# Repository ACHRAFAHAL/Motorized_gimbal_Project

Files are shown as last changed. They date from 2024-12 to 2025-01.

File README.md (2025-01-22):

# Motorized_gimbal_Project

Motorized 3-axis gimbal using Arduino! This project stabilizes cameras with gyroscopic sensors and servomotors for smooth footage.

## Project Overview:
The project is a gimbal system created using an Arduino platform to stabilize a mounted payload (camera) and maintain its orientation. The gimbal compensates for external movements, ensuring smooth, stable footage or data collection.



## Components Used:
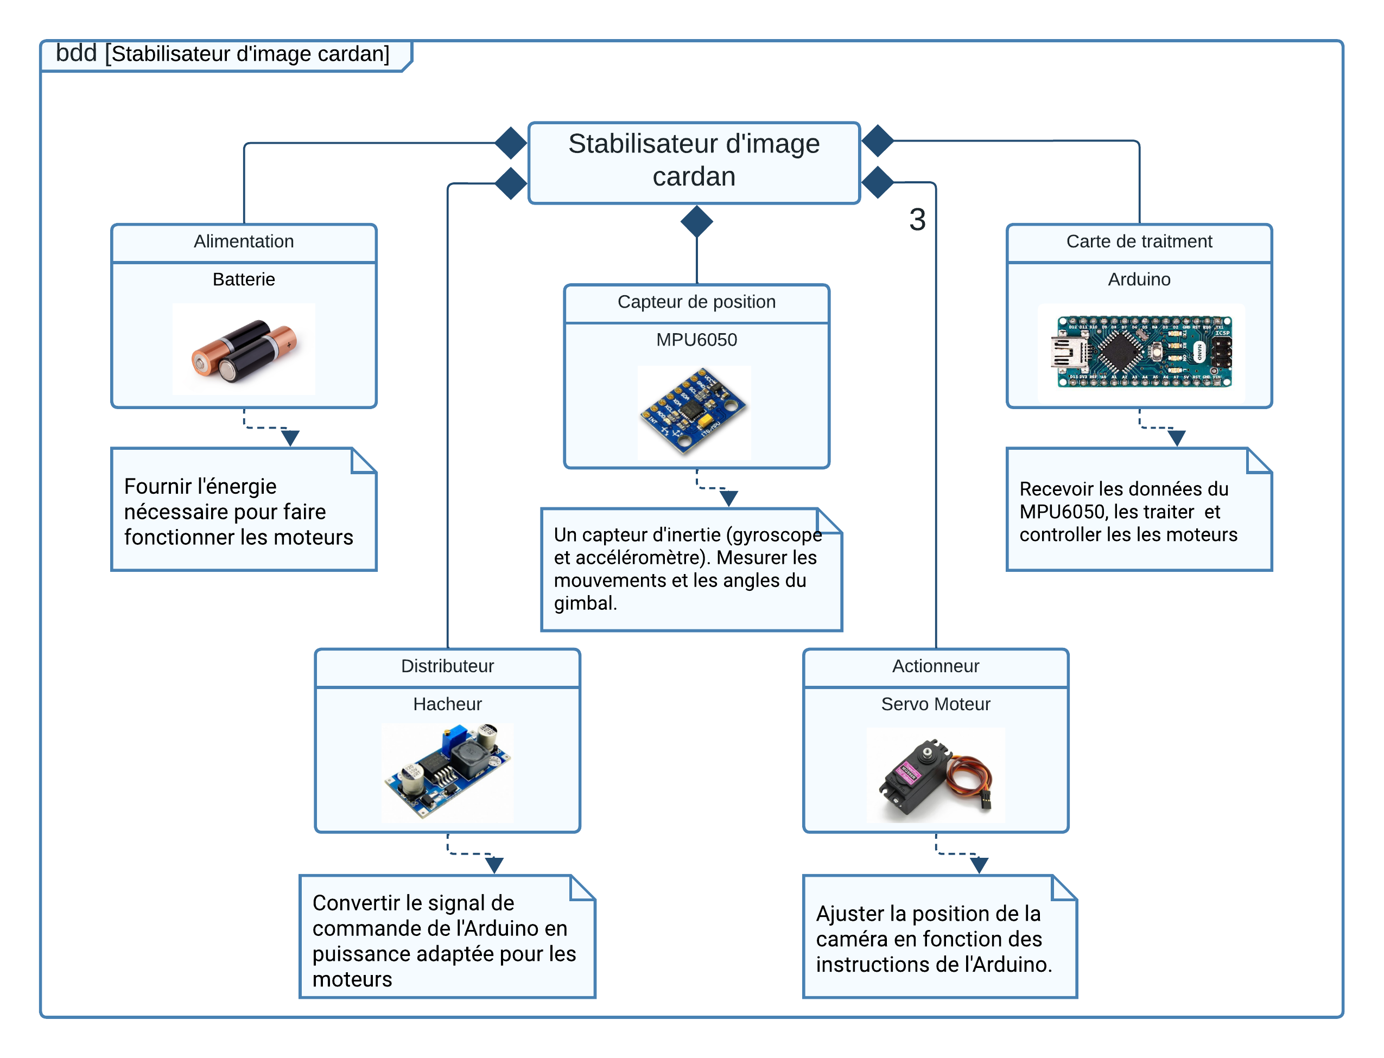
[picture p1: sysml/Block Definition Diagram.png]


[Arduino NANO board](https://www.amazon.com/LAFVIN-Board-ATmega328P-Micro-Controller-Arduino/dp/B07G99NNXL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)

[MPU6050 IMU sensors](https://www.amazon.com/MPU-6050-MPU6050-Accelerometer-Gyroscope-Converter/dp/B07RXQGGJX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) (Accelerometer and Gyroscope) for motion detection

Motors ([servomotors: MG996R](https://www.amazon.com/MG996R-Digital-Waterproof-Airplane-Helicopter/dp/B0DCK462XZ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)) for controlling the pitch, yaw, and roll axes

Power supply (battery)

[Lm2596 DC-DC regulator](https://www.amazon.com/Regulator-Adjustable-Converter-Electronic-Stabilizer/dp/B07PDGG84B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)

## circuit :


## Key Features:
Uses combined accelerometer and gyroscope data for stable orientation estimation. Adjusts motor positions based on feedback from the IMU sensors to stabilize the payload. Real-time sensor data processing ensures smooth stabilization with minimal delay.

## Challenges & Solutions:
Sensor Calibration: Ensured proper calibration of the MPU6050 for accurate readings.
Angle estimation : Eliminating the drift and noise of the estimated angles signal.
Motor Control: Fine-tuned motor response to avoid overshooting and ensure precise stabilization.

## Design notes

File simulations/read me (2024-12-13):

To run the .ino code files you can simply use the arduino IDE
link to download: https://www.arduino.cc/en/software

To run the .pde code files you must download processing IDE
link to download: https://processing.org/download

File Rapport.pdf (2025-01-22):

## Thème : Jeux, sports

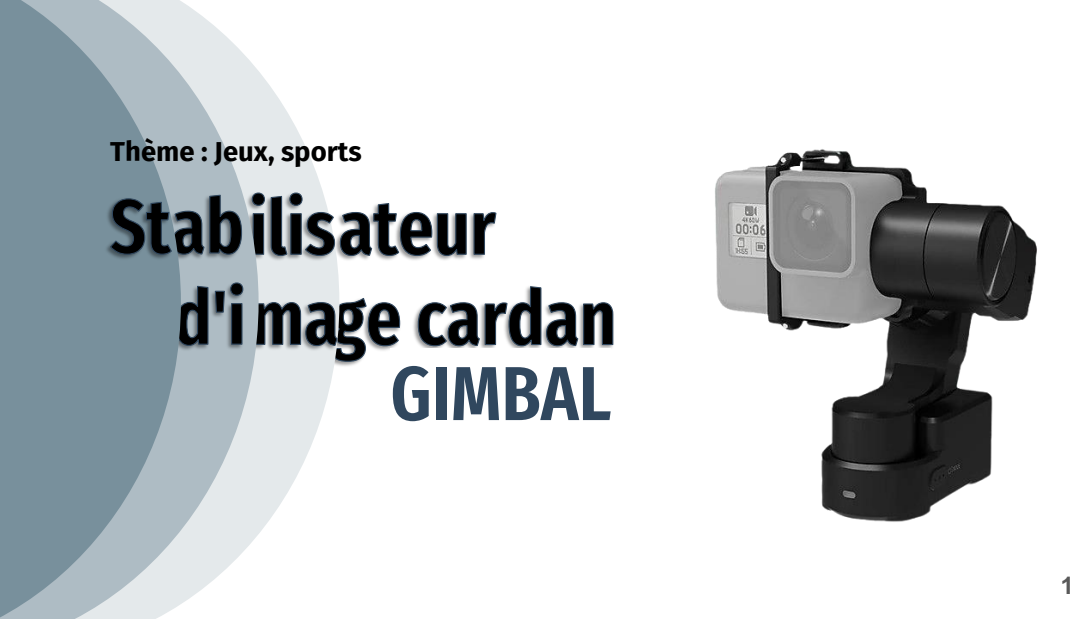
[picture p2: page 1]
ge cardan; ateur ma; ilis; GIMBAL; Stab

TIPE : AHAL Achraf
№ SCEI : 29114

2

## 1 Introduction

## 2 Problématique

## 3 Objectifs

## 4 Conclusion

### 3.1 Modélisation du système

et choix du moteur

### 3.2 Détecter les mouvements indésirables

de la caméra

### 3.3 Optimisation et choix du matériau de

la plateforme porte-camera

### 3.4 Réalisation d’un prototype

# INTRODUCTION

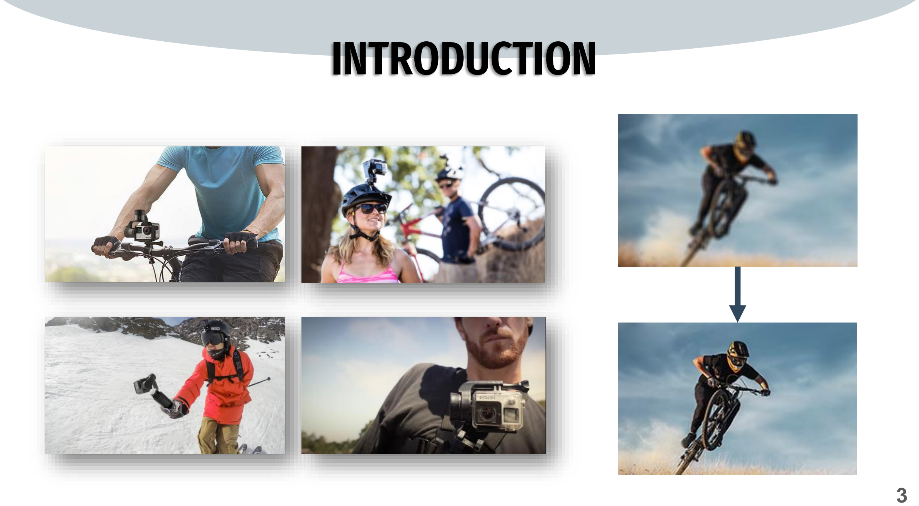
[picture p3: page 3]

3

# PROBLÉMATIQUE

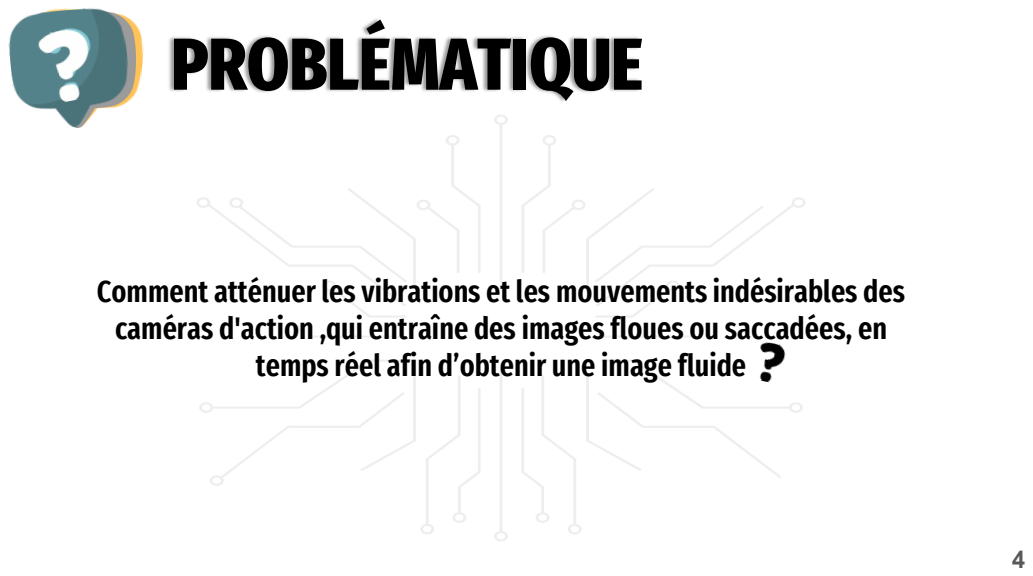
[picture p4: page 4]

Comment atténuer les vibrations et les mouvements indésirables des
caméras d'action ,qui entraîne des images floues ou saccadées, en

temps réel afin d’obtenir une image fluide

OBJECTIFS | 01

Modélisation du système et choix du moteur
02

Détecter les mouvements indésirables de la caméra
03

Optimisation et choix du matériau de la plateforme porte-camera
04

Réalisation d’un prototype

5

6

# OBJECTIF 1

# Modélisation du système et choix du moteur

## Représentations SysMl

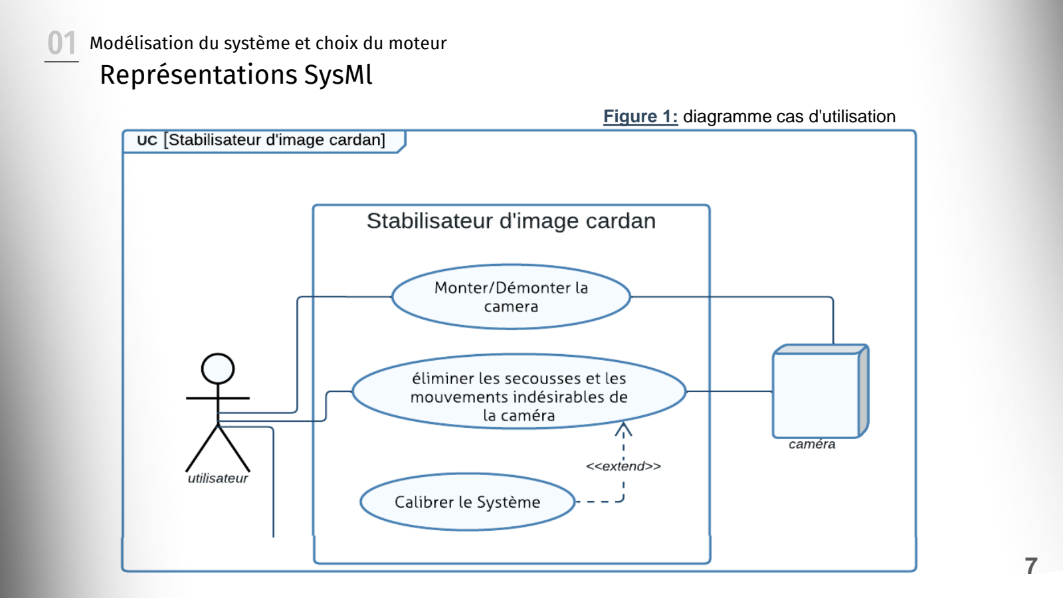
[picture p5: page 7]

01 Modélisation du système et choix du moteur

Figure 1: diagramme cas d'utilisation

7

## Représentations SysMl

01 Modélisation du système et choix du moteur

Figure 2: diagramme des exigences

8

## Représentations SysMl

01 Modélisation du système et choix du moteur

Figure 3:
diagramme de
definition des blocs

9

## Modélisation

Gravité | Gravité | Gravité | Gravité
| Liaison pivot
(O1, Z1)
| | Liaison pivot
(O2, Y2)
| | | Liaison pivot
(O3, X3)

Porteur

C12 | C23 | C34

Figure 6: graphe de liaisons

01 Modélisation du système et choix du moteur

Figure 5: schéma cinématique

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
HYPOTHÈSES :

- On néglige les effets du frottement dans les joints du gimbal
- Les liaisons sont parfaits
- On suppose que les masses sont concentrées aux centres de gravité de la caméra et des platformes

# m = 3 ⇒ On exige 3 moteurs

## Modélisation

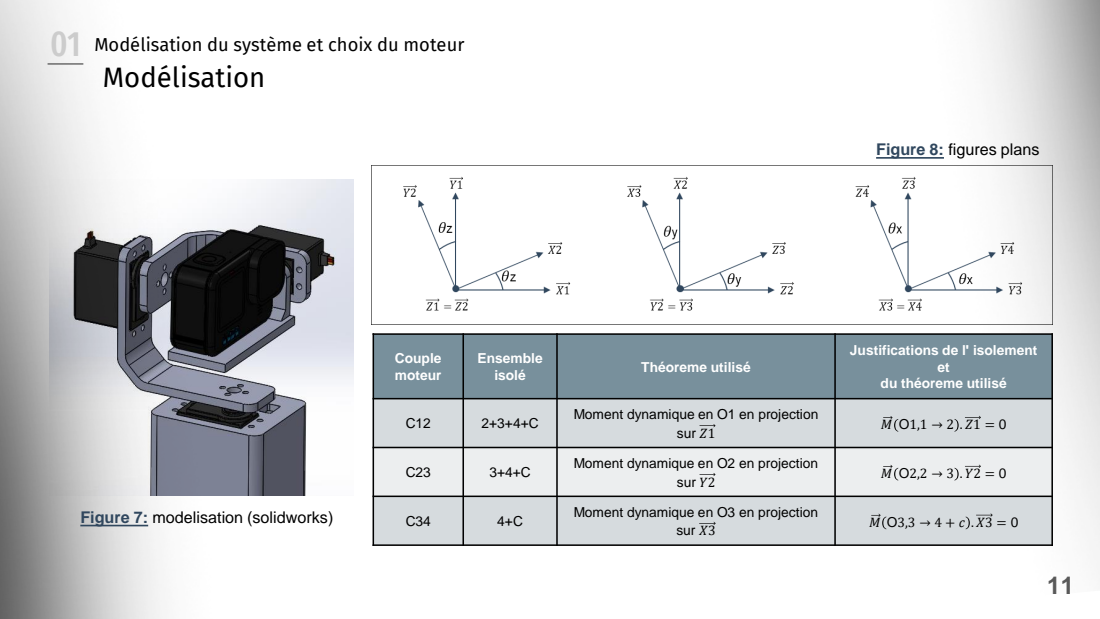
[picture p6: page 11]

01 Modélisation du système et choix du moteur

Figure 8: figures plans

Couple moteur | Ensemble isolé | Théoreme utilisé | Justifications de l' isolement et du théoreme utilisé

C12 | 2+3+4+C | Moment dynamique en O1 en projection sur Z1 | M O1,1 → 2 . Z1 = 0

C23 | 3+4+C | Moment dynamique en O2 en projection sur Y2 | M O2,2 → 3 . Y2 = 0

C34 | 4+C | Moment dynamique en O3 en projection sur X3 | M O3,3 → 4 + c . X3 = 0

Figure 7: modelisation (solidworks)

## Calcule de C12 (Théorie)

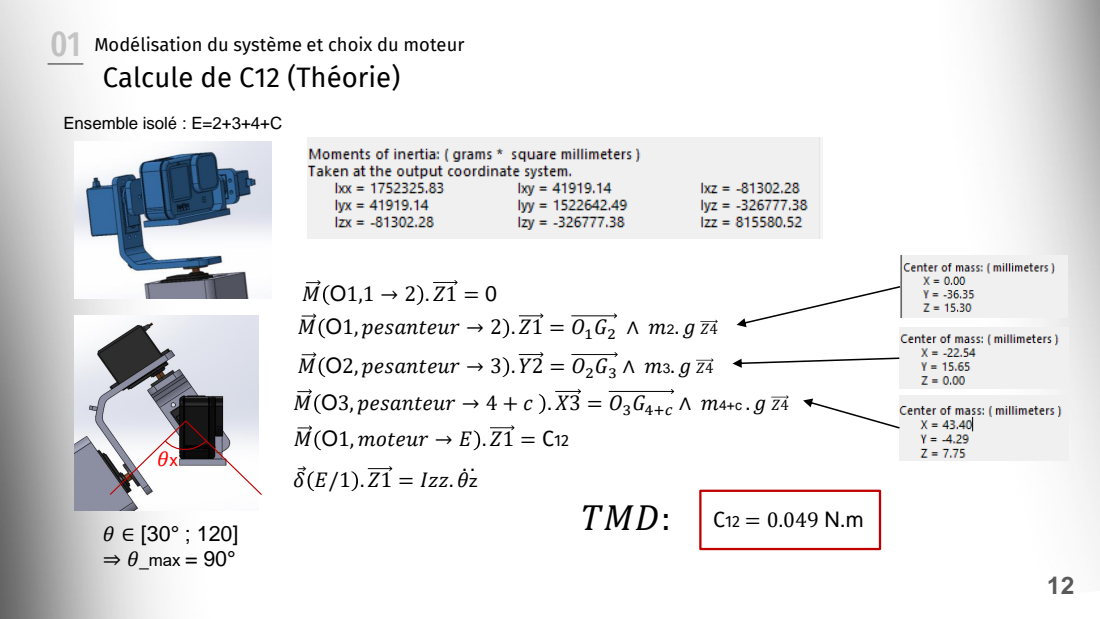
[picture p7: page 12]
Ensemble isolé : E=2+3+4+C; M O1, pesanteur → 2 . Z1 = O1G2 ∧ m2. g Z4; M O1, moteur → E . Z1 = C12; δԦ E/1 . Z1 = Izz. θz; TMD:; ⇒ θ_max = 90°; M O2, pesanteur → 3 . Y2 = O2G3 ∧ m3. g Z4; M O3, pesanteur → 4 + c . X3 = O3G4+c ∧ m4+c . g Z4

01 Modélisation du système et choix du moteur

## Calcule de C12 (Simulation)

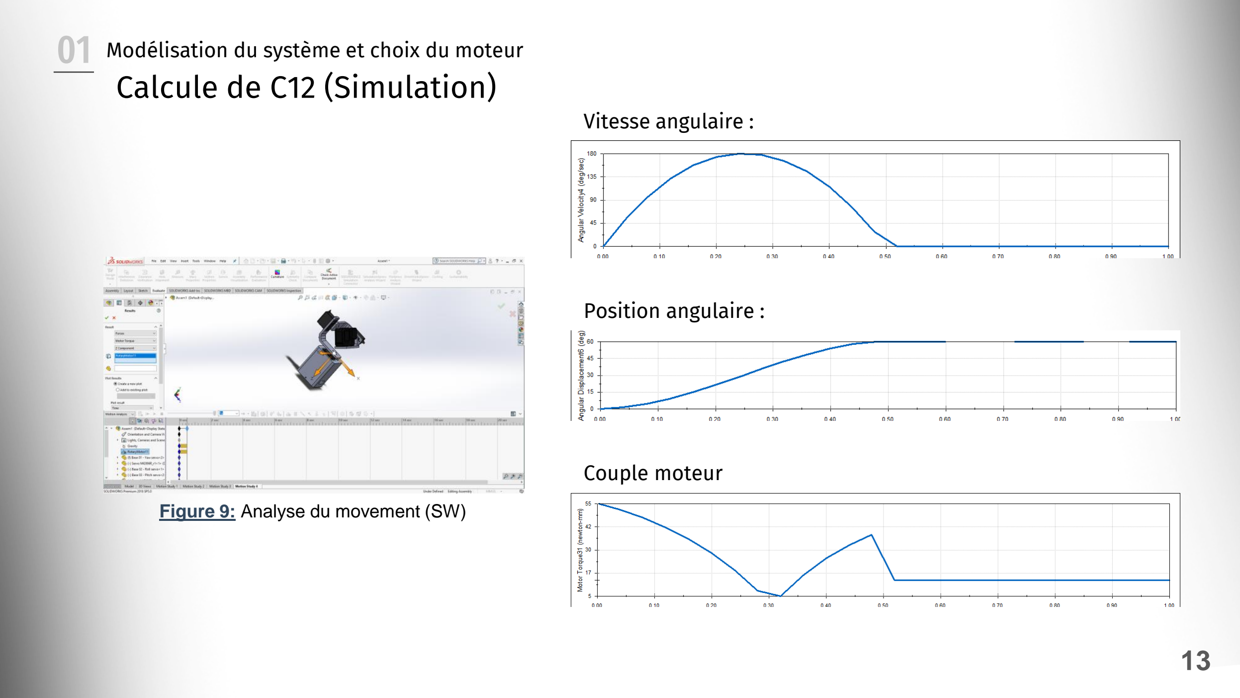
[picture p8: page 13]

01 Modélisation du système et choix du moteur

13

Vitesse angulaire :

Position angulaire :

Couple moteur

Figure 9: Analyse du movement (SW)

## Calcule de C23 et C34 (Simulation)

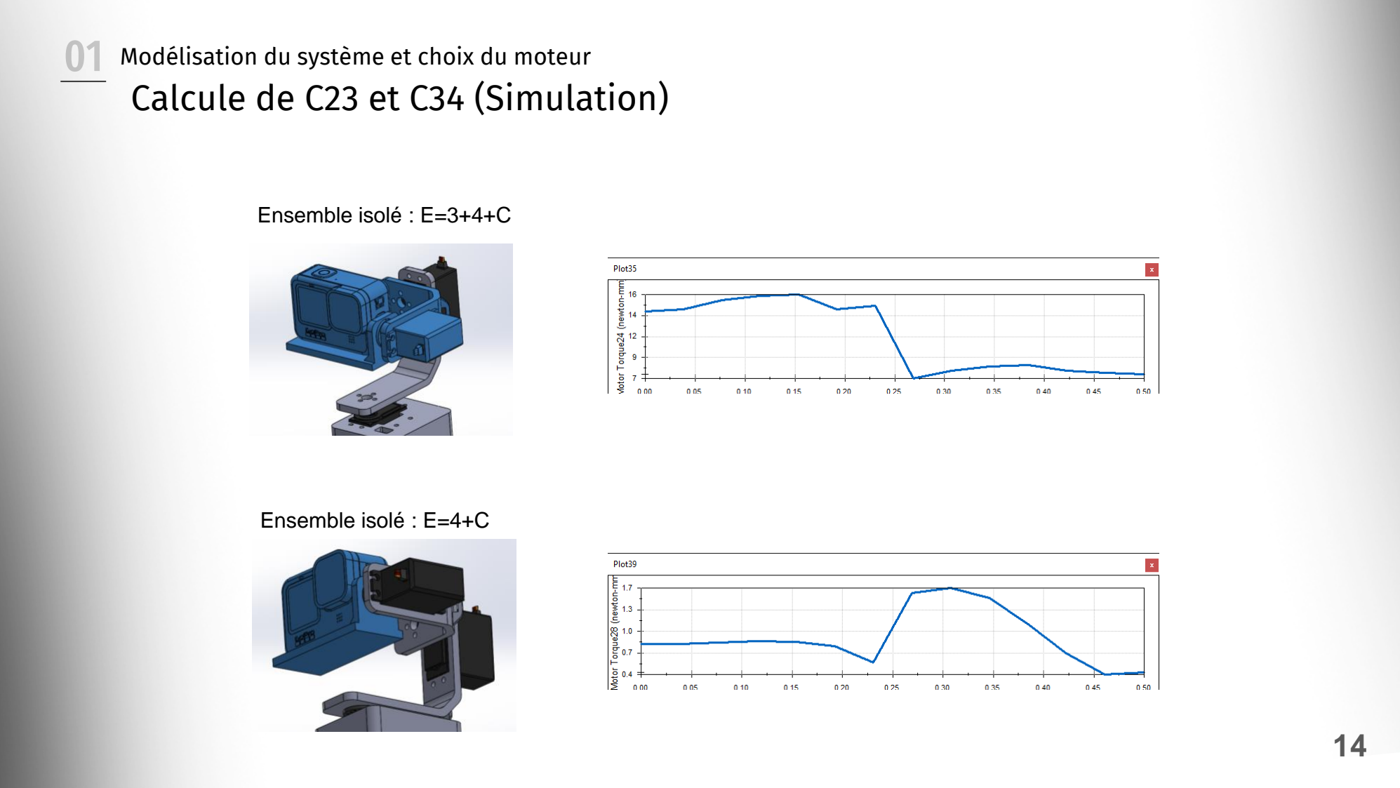
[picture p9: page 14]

01 Modélisation du système et choix du moteur

14

Ensemble isolé : E=3+4+C

Ensemble isolé : E=4+C

## Choix des moteurs et conclusion

01 Modélisation du système et choix du moteur

15

•Modèle : SG90

•Dimensions : 22 x 11,5 x 27 mm

•Poids : 9g

•Vitesse: 0.12 sec/60° sous 4.8V

•Couple: 1.2Kg/cm sous 4.8V

•Tension: 4.8V – 6V

•Modèle : MG995

•Dimensions : 40,7 x 19,7 x 42,9 mm

•Poids : 55g

•Vitesse: 0.14 sec/60° sous 6.0V

•Couple : 6V 10.5 kg/cm

•Tension : 3,0V – 7,2V

•Modèle : MG996R

•Dimensions : 40,7 x 19,7 x 42,9 mm

•Poids : 55g

•Vitesse: 0.16 sec/60° sous 6.0V

•Couple : 6V 11kg/cm

•Tension : 3,0V – 7,2V

16

# OBJECTIF 2

# Détecter les mouvements Indésirables de la caméra

## Acquisition des angles (Théorie)

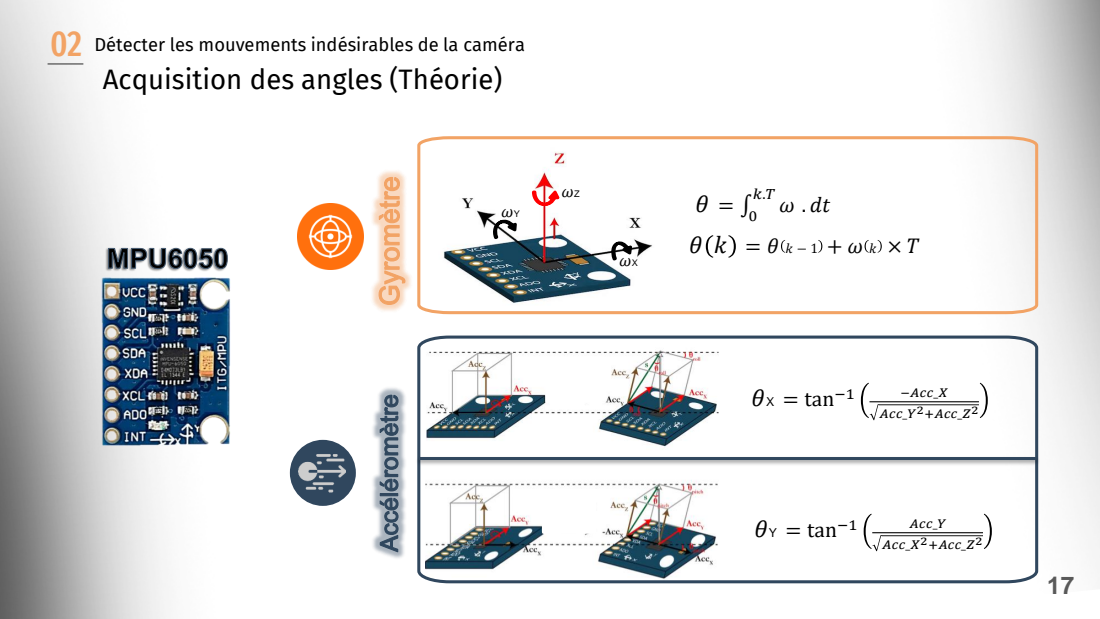
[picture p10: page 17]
θX = tan⁻¹; −Acc_X; Acc_Y2+Acc_Z2; θY = tan⁻¹; Acc_Y; Acc_X2+Acc_Z2; Gyromètre Accéléromètre; MPU6050

02 Détecter les mouvements indésirables de la caméra

## MONTAGE EXPÉRIMENTAL 1

## Calibrage du capteur

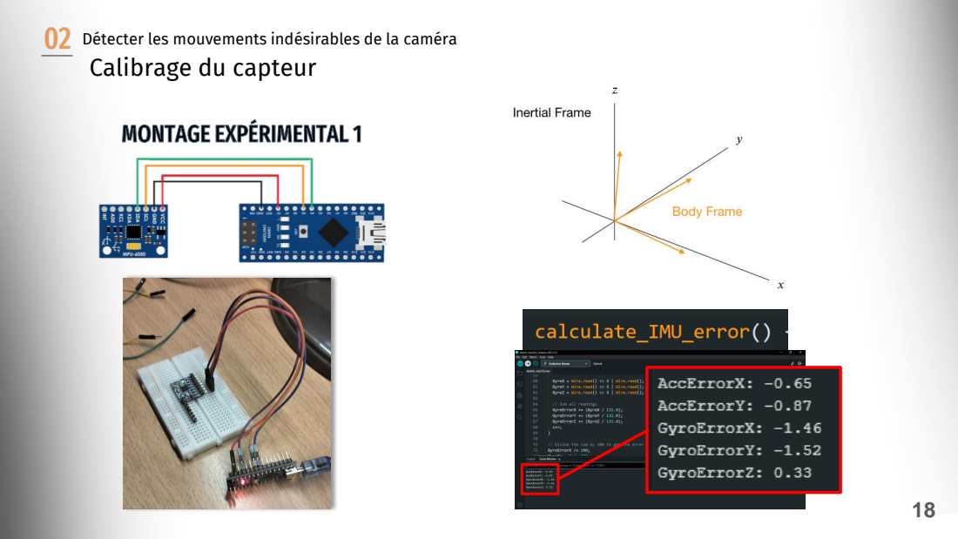
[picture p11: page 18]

02 Détecter les mouvements indésirables de la caméra

## Acquisition des angles (Experience)

Gyromètre | Accéléromètre

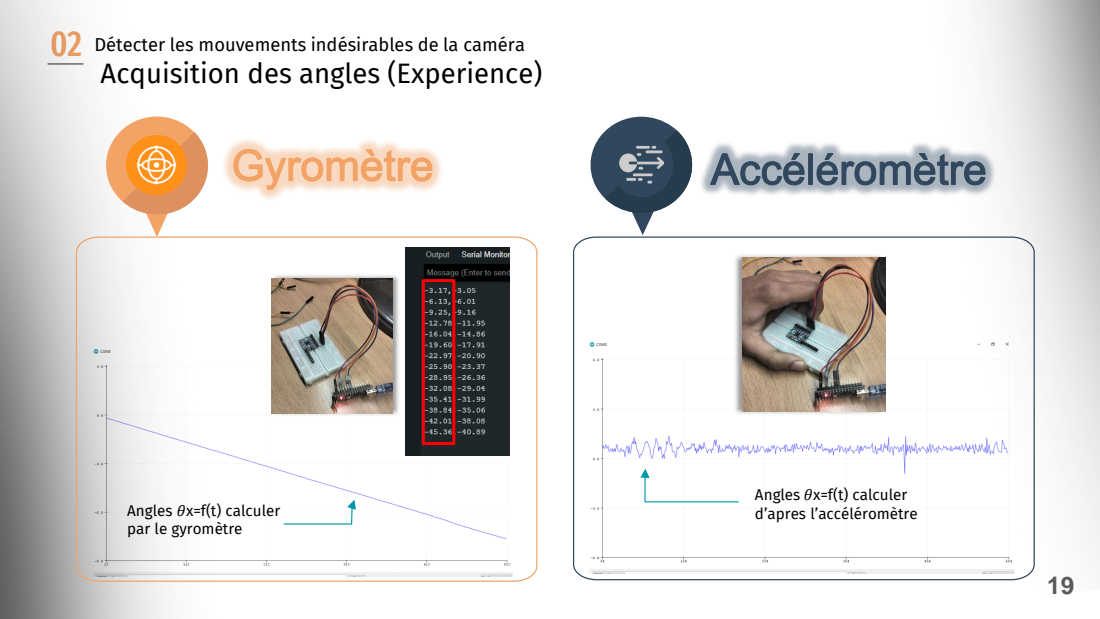
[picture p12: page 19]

02 Détecter les mouvements indésirables de la caméra

Angles θx=f(t) calculer
d’apres l’accéléromètre

par le gyromètre

## Filtrage (passe bas accéléromètre)

02 Détecter les mouvements indésirables de la caméra

20

Angle réelle : 35°

accfiltre | n | = α accfiltre | n − 1 | + 1 − α acc | n

⇒ α =

∆t
τ + ∆t

⇒ ∆t =

1
fs
⇒ τ = 2πfs | ⇒ fs= 100 Hz

## Filtrage (par fusion)

FILTRE PASSE-HAUT

FILTRE PASSE-BAS

02 Détecter les mouvements indésirables de la caméra

## Filtre complémentaire: θ =

T
1+ T

θ +

1
1+ T
(θ | + Ω . T)
On pose : | α =

1
1+ T
θ = 1 − α θ | + α [θ | k − 1 + Ω | k × kT]

21

## Choix de α

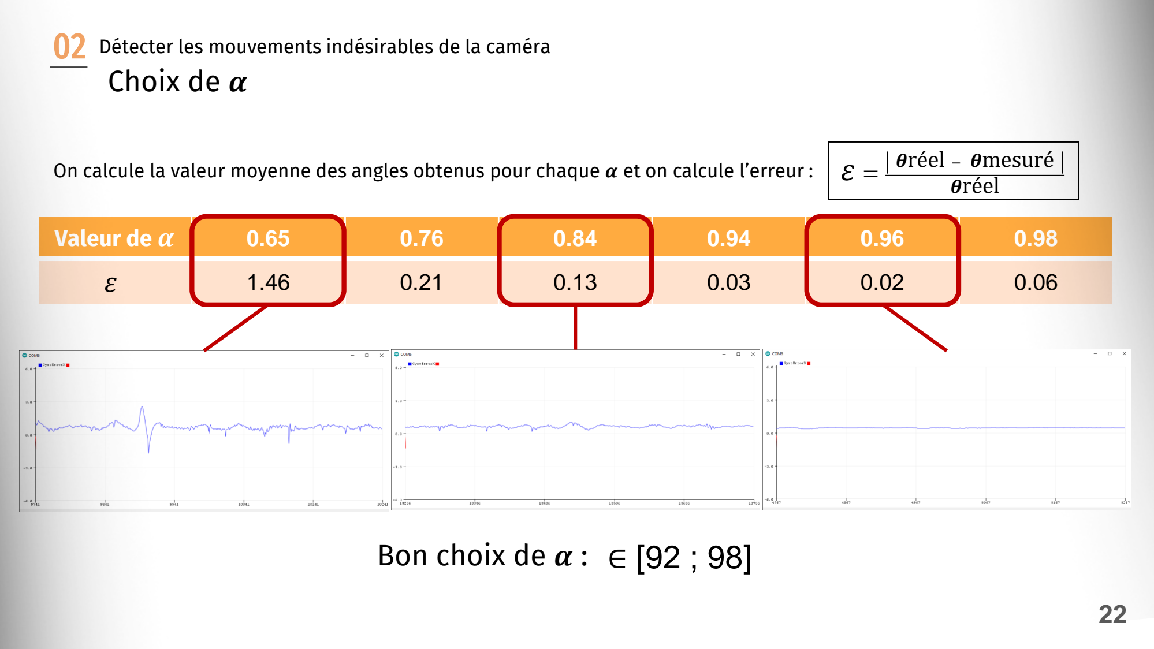
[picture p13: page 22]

Valeur de α | 0.65 | 0.76 | 0.84 | 0.94 | 0.96 | 0.98
ε | 1.46 | 0.21 | 0.13 | 0.03 | 0.02 | 0.06

02 Détecter les mouvements indésirables de la caméra

On calcule la valeur moyenne des angles obtenus pour chaque α et on calcule l’erreur : ε =

θréel − θmesuré
θréel

22

## Bon choix de α : ∈ [92 ; 98]

## Filtrage (par fusion)

02 Détecter les mouvements indésirables de la caméra

Angles θx=f(t) calculer
en fusion

23

Figure 10: sortie du filter complémentaire

## Résultats et simulation

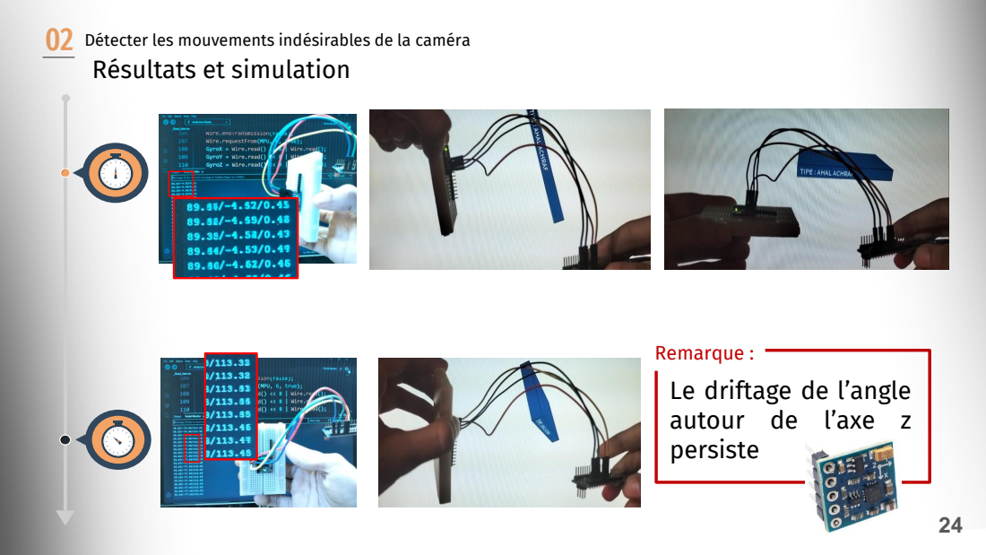
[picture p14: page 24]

02 Détecter les mouvements indésirables de la caméra

Remarque :
Le driftage de l’angle
autour de l’axe z
persiste

## DMP (Traitement numérique du mouvement)

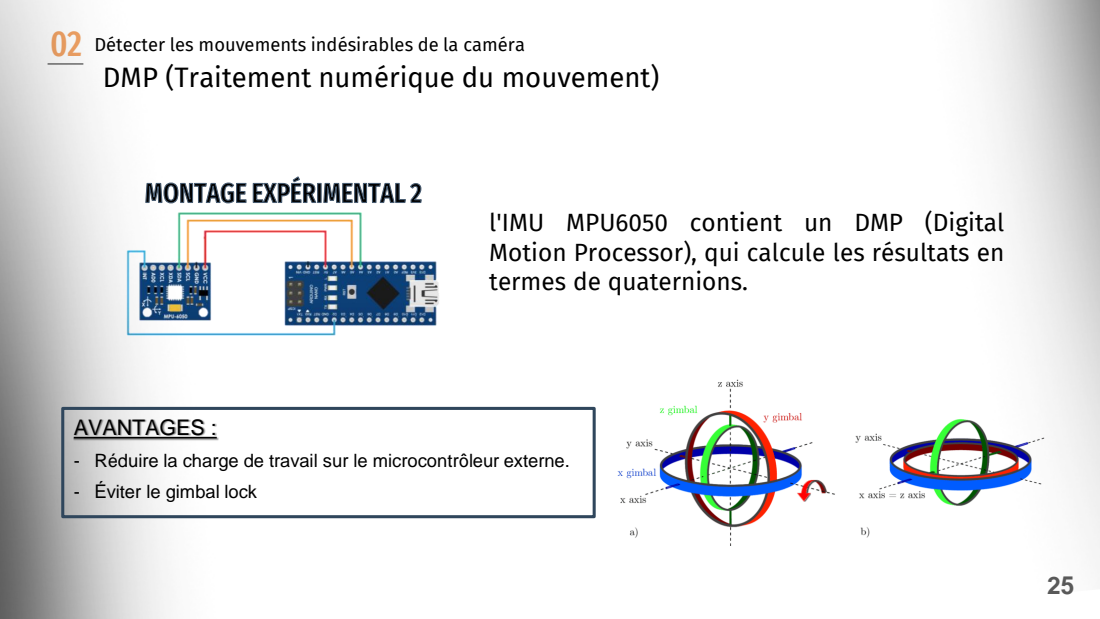
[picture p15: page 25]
AVANTAGES :; MONTAGE EXPÉRIMENTAL 2

02 Détecter les mouvements indésirables de la caméra

l'IMU MPU6050 contient un DMP (Digital
Motion Processor), qui calcule les résultats en
termes de quaternions.

- Réduire la charge de travail sur le microcontrôleur externe.
- Éviter le gimbal lock

## Simulation et conclusion

02 Détecter les mouvements indésirables de la caméra

26

## Le DMP assure une précision plus élevée que celle obtenue par la fusion des

données via un filtre complémentaire.

# OBJECTIF 3

# Optimisation et choix du Matériau de la plateforme Porte-camera

## Modélisation de la sollicitation

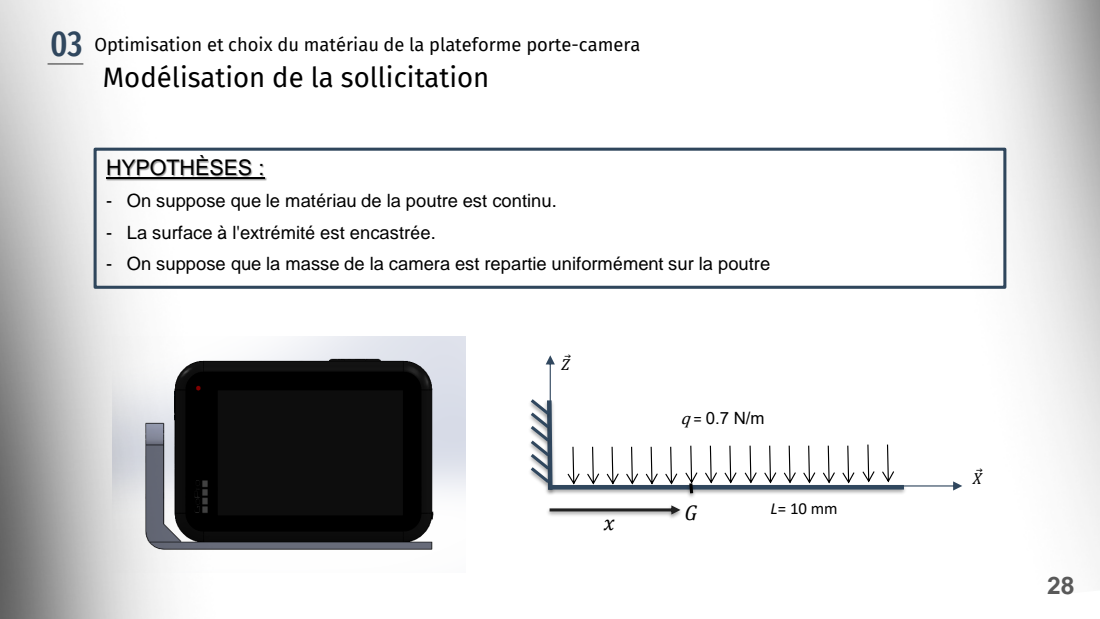
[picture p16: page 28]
HYPOTHÈSES :

03 Optimisation et choix du matériau de la plateforme porte-camera

- On suppose que le matériau de la poutre est continu.
- La surface à l'extrémité est encastrée.
- On suppose que la masse de la camera est repartie uniformément sur la poutre

Ԧ

## Torseur de cohésion

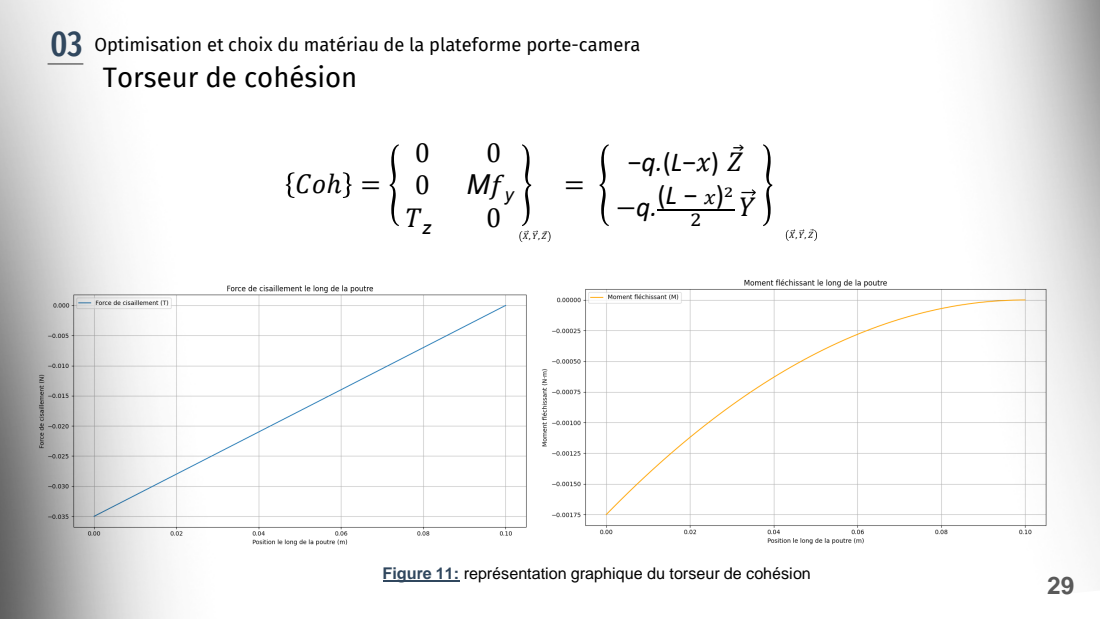
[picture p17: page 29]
Coℎ =; Mfy

03 Optimisation et choix du matériau de la plateforme porte-camera

Figure 11: représentation graphique du torseur de cohésion

## Démarche

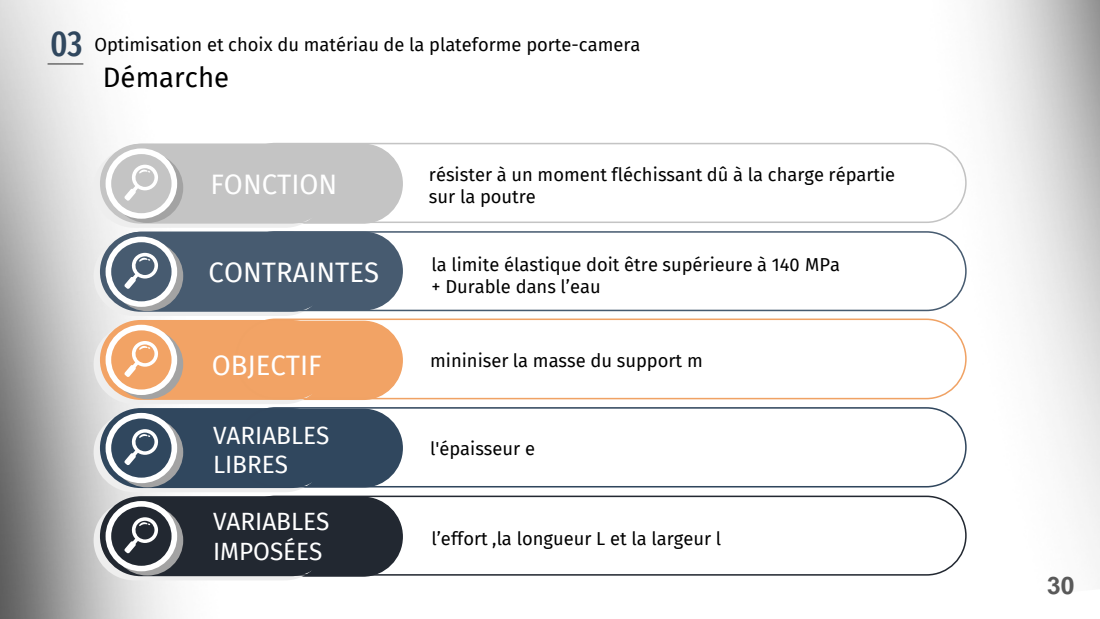
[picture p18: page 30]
VARIABLES IMPOSÉES; FONCTION; CONTRAINTES; OBJECTIF; VARIABLES LIBRES; l'épaisseur e

03 Optimisation et choix du matériau de la plateforme porte-camera

résister à un moment fléchissant dû à la charge répartie
sur la poutre

la limite élastique doit être supérieure à 140 MPa
+ Durable dans l’eau

mininiser la masse du support m

l’effort ,la longueur L et la largeur l

## Indice de performance

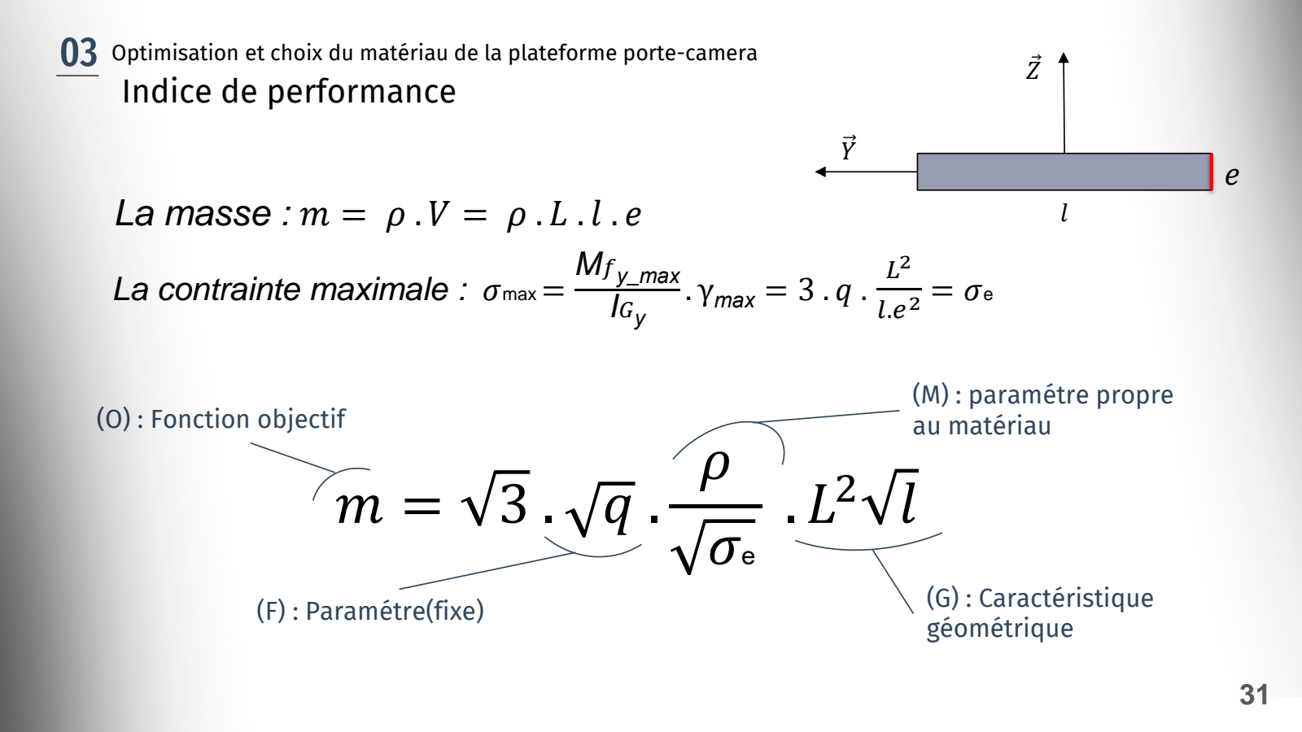
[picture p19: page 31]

m = 3 . q .

ρ
σe

. L

2
l
(O) : Fonction objectif
(F) : Paramétre(fixe)
(M) : paramétre propre
au matériau
(G) : Caractéristique
géométrique

31

## La masse : m = ρ . V = ρ . L . l . e

La contrainte maximale : σmax =

Mfy max

IGy

. γmax

= 3 . q .

L

2
l.e

2

= σe

Y

ZԦ

e
l

03 Optimisation et choix du matériau de la plateforme porte-camera

Indice de performance : | ⟹ | logσe = 2 log ρ + log I

## Diagramme d'ashby

32

I =

σe

1
2
ρ

03 Optimisation et choix du matériau de la plateforme porte-camera

Figure 12: diagramme d'ashby

## Choix du matériau

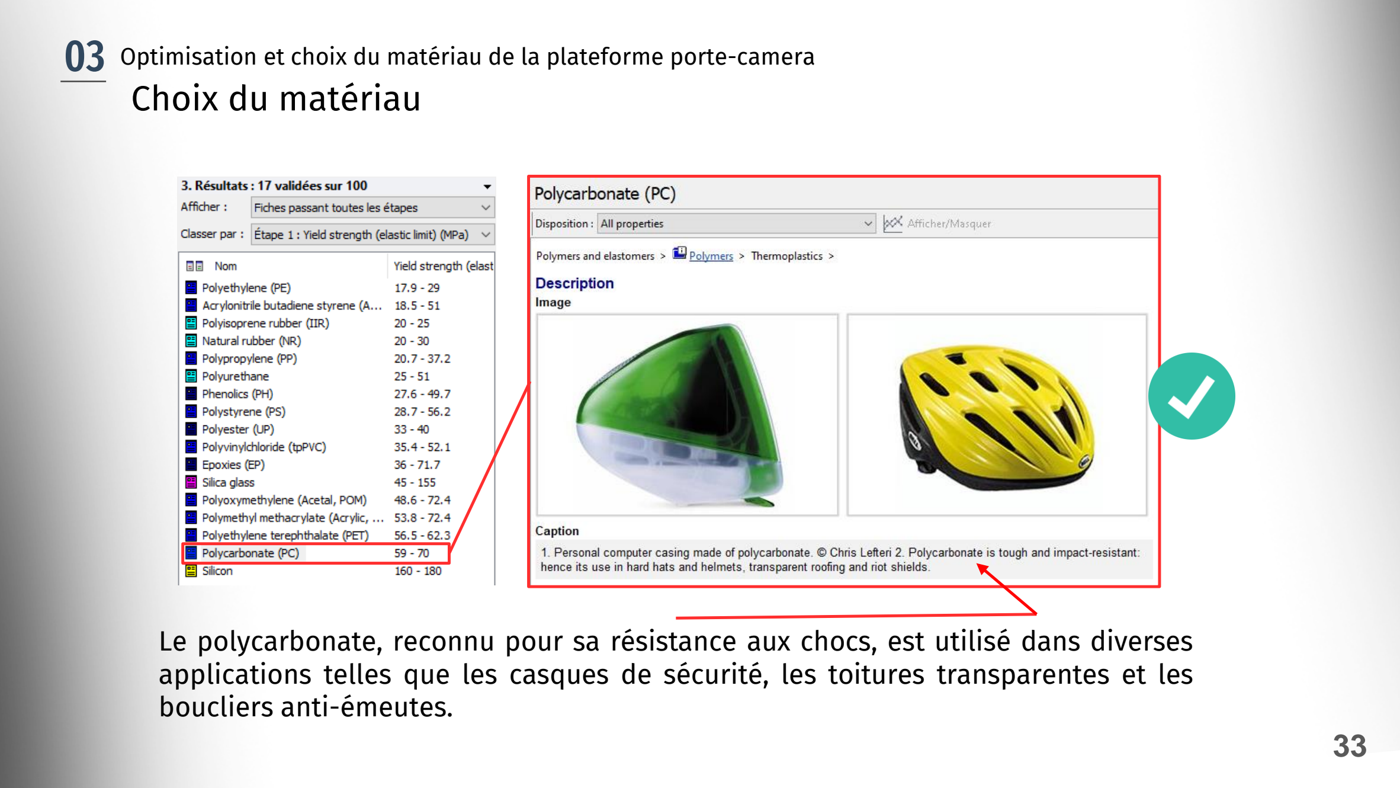
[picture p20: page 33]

33

Le polycarbonate, reconnu pour sa résistance aux chocs, est utilisé dans diverses applications telles que les casques de sécurité, les toitures transparentes et les boucliers anti-émeutes.

03 Optimisation et choix du matériau de la plateforme porte-camera

## Détermination de I'épaisseur minimale

34

## Condition de resistance : σmax =

Mfy max

IGy

### . γmax ≤

σe

s

e ≥ 3 . q .

s. L

2

## l .σe

1/2
⟹
⟹ | e ≥ 0.1722mm
Données : | q = 0.7 N/m | L = 10 cm | l = 3.6 cm | s = 3

### e = 1 mm

03 Optimisation et choix du matériau de la plateforme porte-camera

## Simulation et conclusion

35

Le polycarbonate :

- résiste au moment fléchissant + résiste aux chocs
- Une structure légère permet des mouvements plus fluides
- résiste aux variations de température + résiste à l'eau
- offre un excellent rapport qualité-prix

03 Optimisation et choix du matériau de la plateforme porte-camera

Figure 13: simulation Xpress (SW)

# OBJECTIF 3

# Réalisation d'un prototype

## Regulation de tension

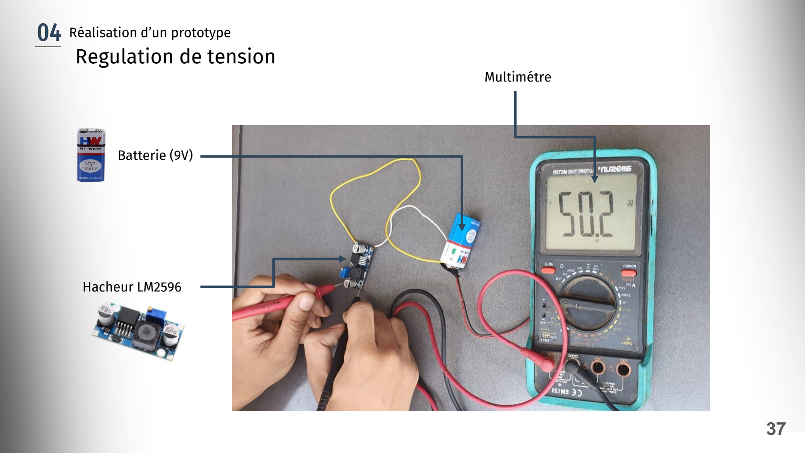
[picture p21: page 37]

37

04 Réalisation d’un prototype

Multimétre

Batterie (9V)

Hacheur LM2596

## Cablage

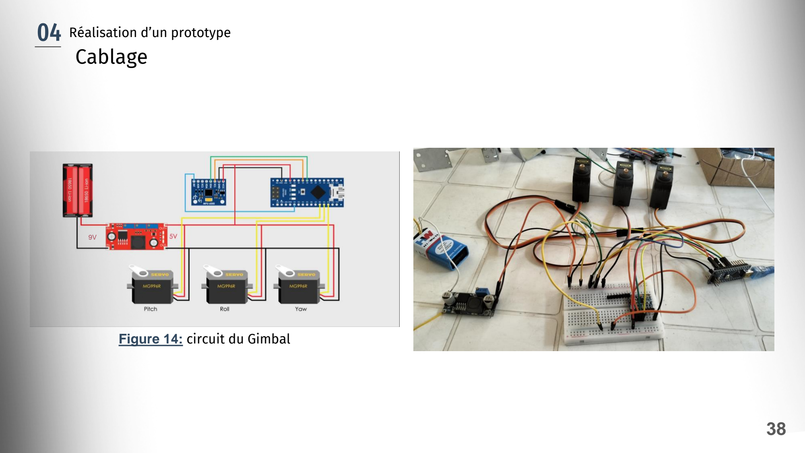
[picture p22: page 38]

9V

38

04 Réalisation d’un prototype

Figure 14: circuit du Gimbal

## Prototype

## MPU-6050

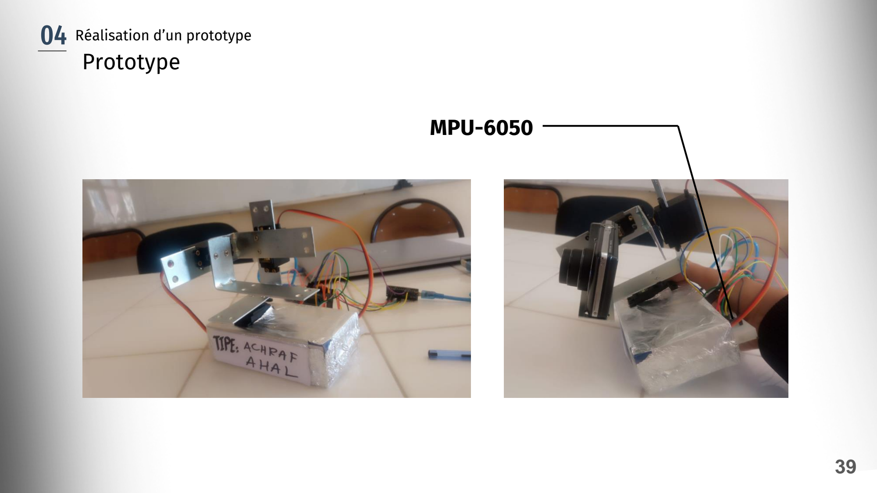
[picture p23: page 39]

39

04 Réalisation d’un prototype

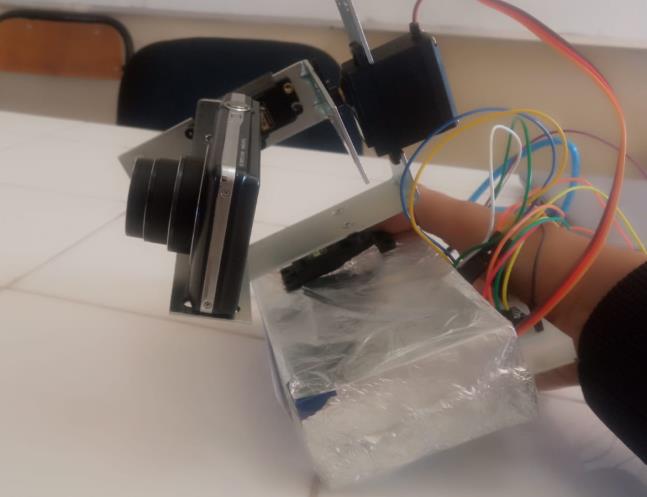
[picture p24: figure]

# CONCLUSION

41

Annexe Calibrage du capteur

42

Annexe Filtrage (passe bas accéléromètre)

43

Annexe Filtrage (par fusion)

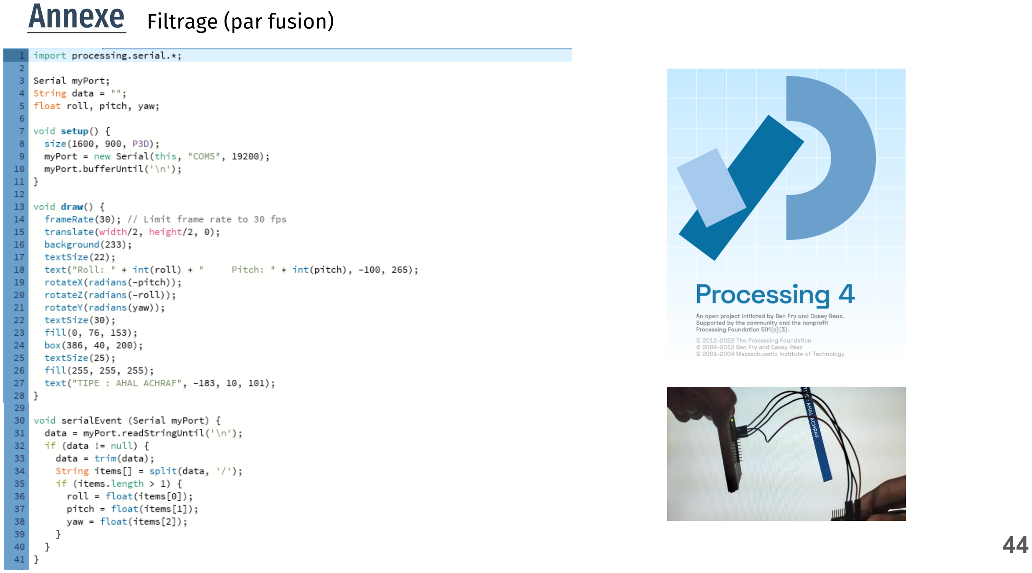
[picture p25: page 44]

44

Annexe Filtrage (par fusion)

45

Annexe Tracage du torseur de cohésion

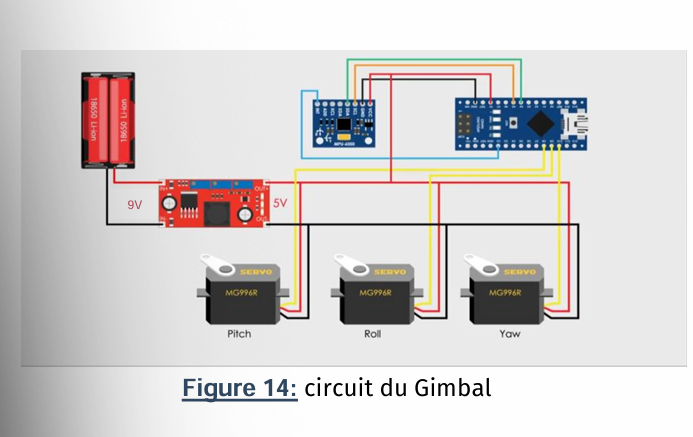
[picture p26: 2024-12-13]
Circuit.png

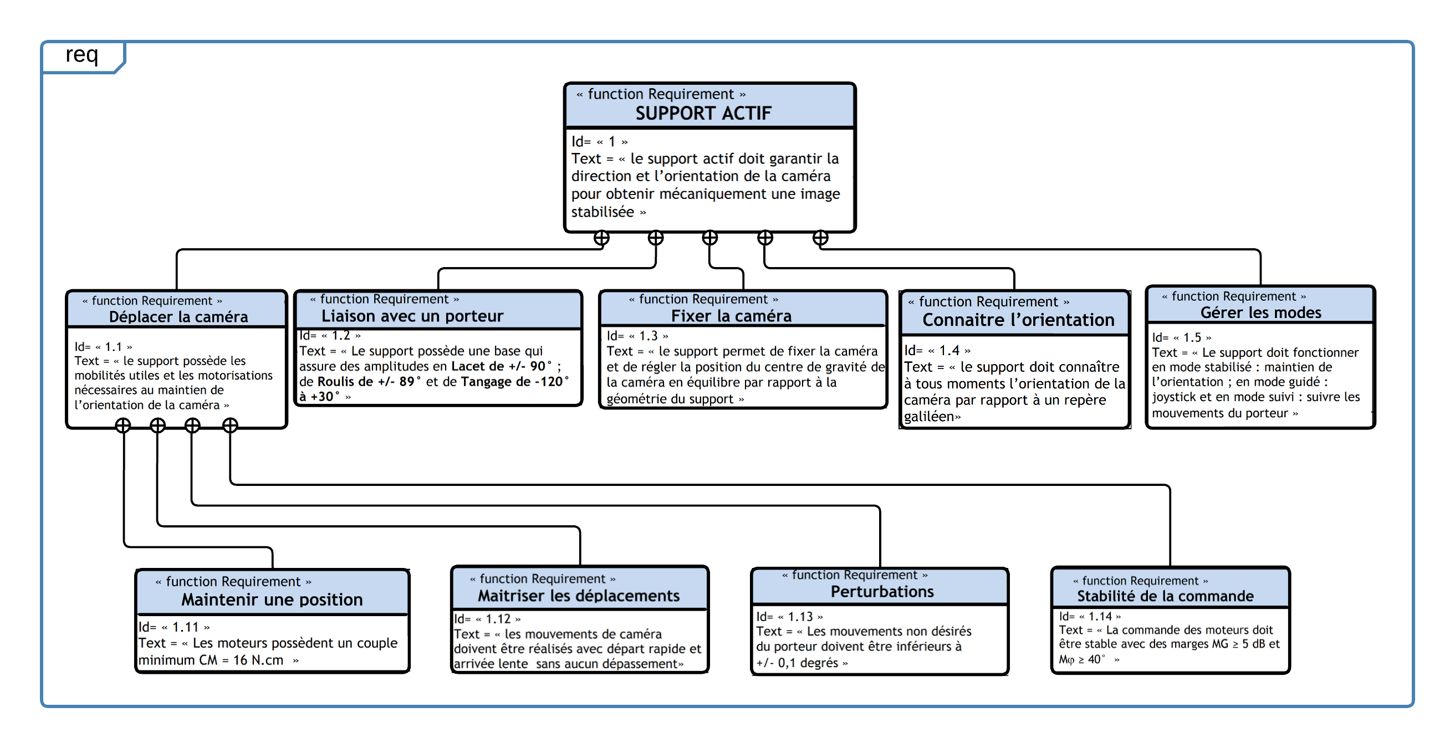
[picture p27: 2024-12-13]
sysml/req diagram.png

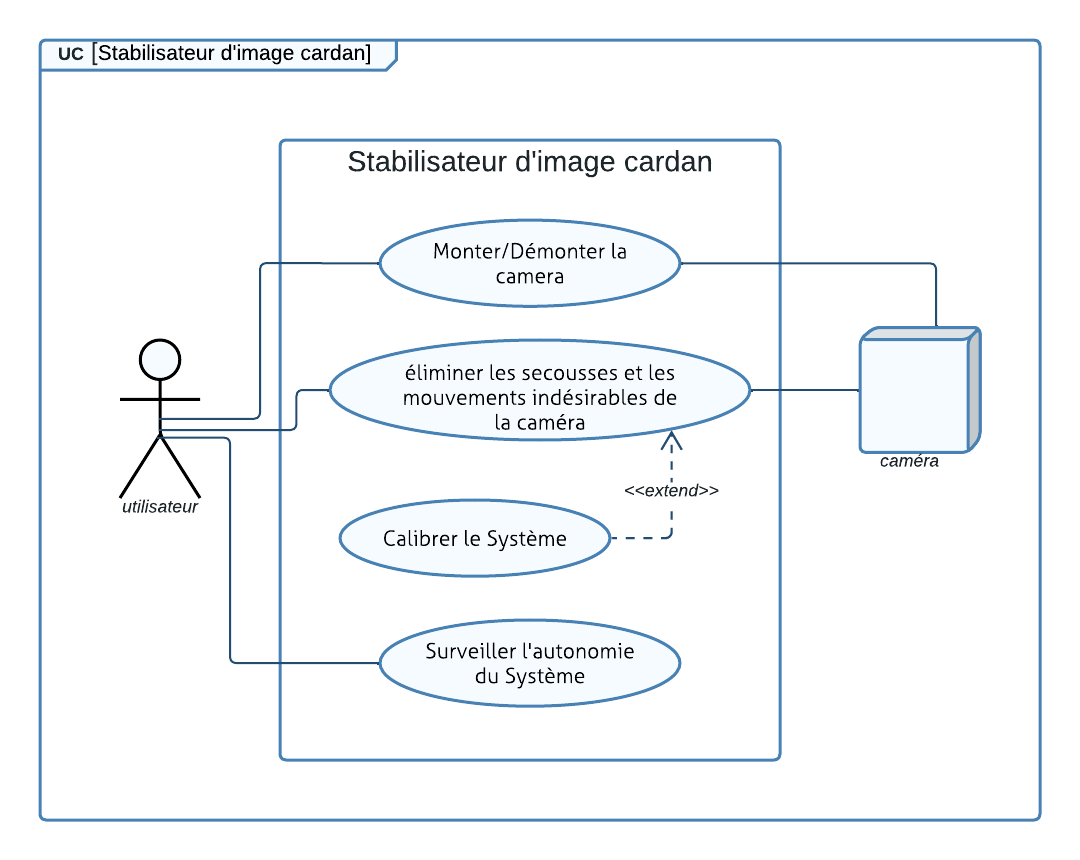
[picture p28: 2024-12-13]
sysml/Use case diagram.png

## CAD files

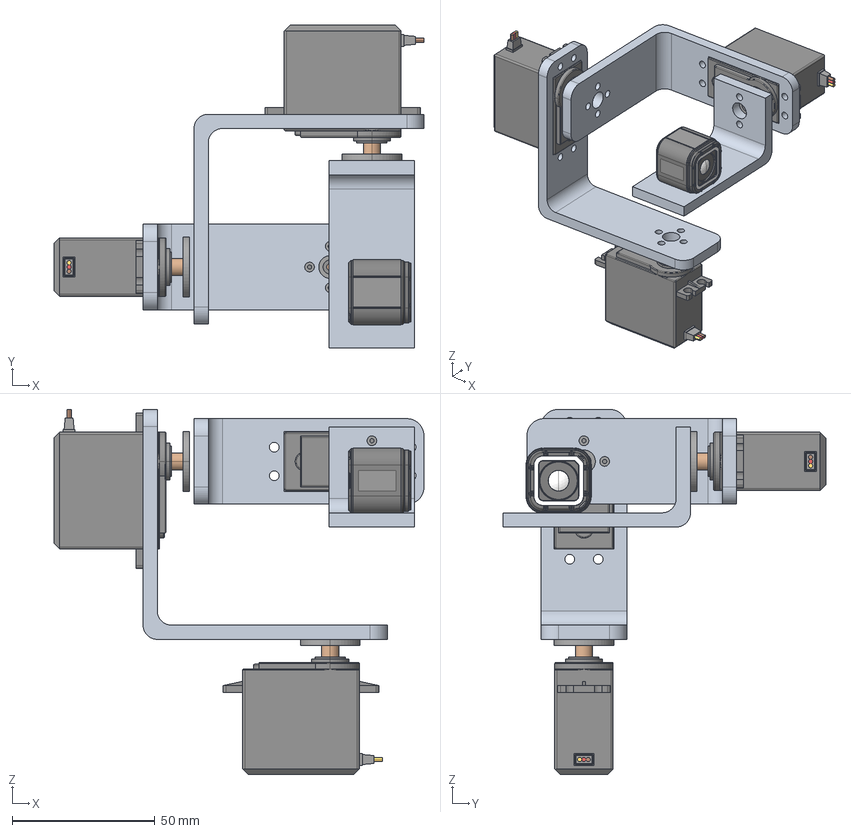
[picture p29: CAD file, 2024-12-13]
3D parts/Gimbal_Assembly.stp
129.7 x 113.0 x 128.0 mm
Servo MG996R_r2 x 3
base 2
base 4
Top platform 1
GoPro Hero4 Session

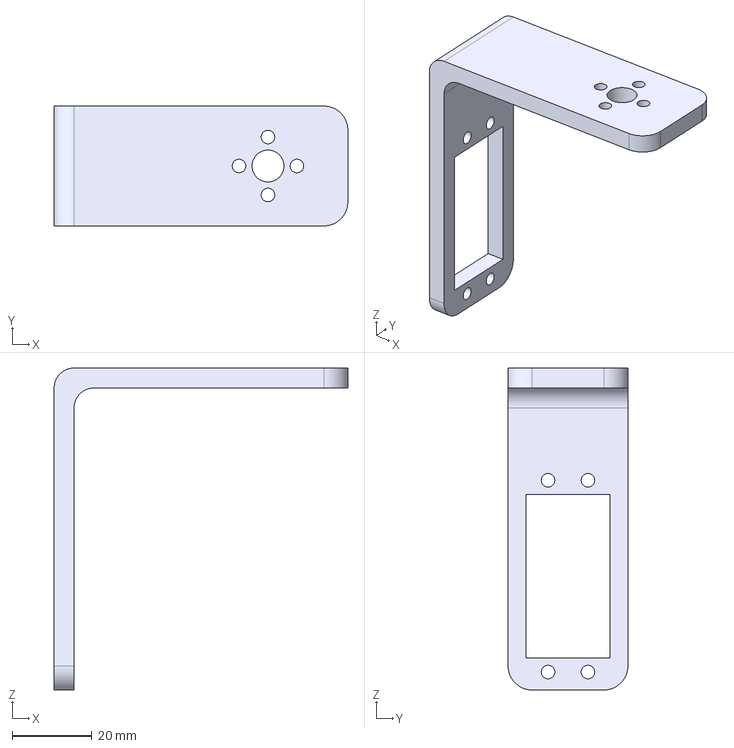
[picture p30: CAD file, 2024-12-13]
3D parts/base 4.stp
73.5 x 30.0 x 80.6 mm

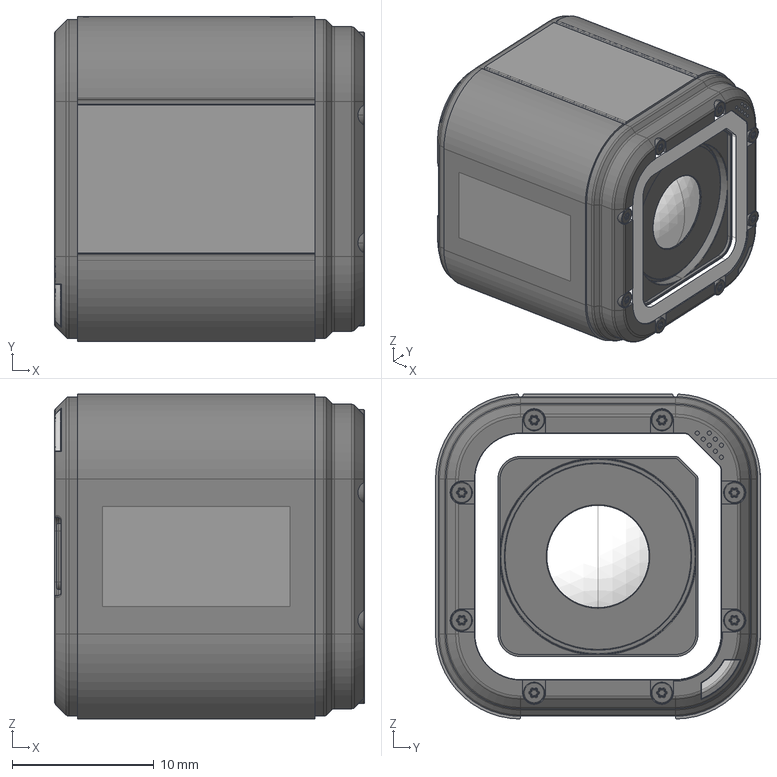
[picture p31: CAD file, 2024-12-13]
3D parts/GoPro Hero4 Session.stp
21.8 x 22.9 x 22.9 mm

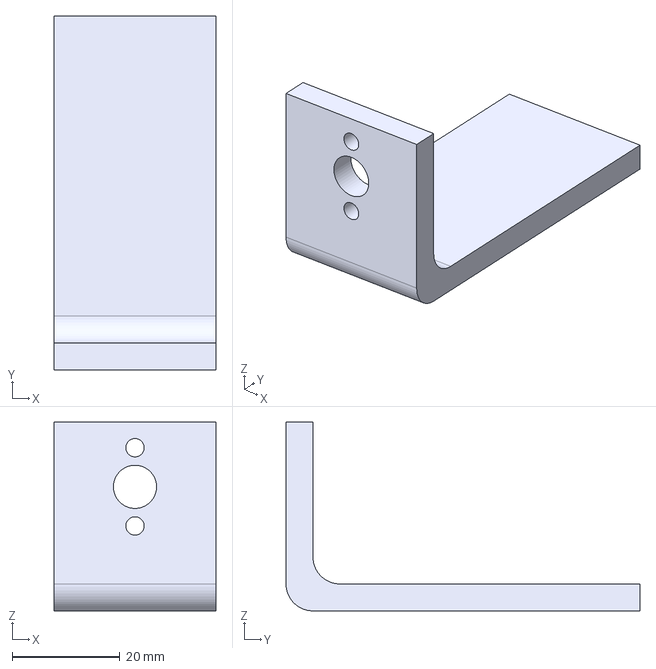
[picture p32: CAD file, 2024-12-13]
3D parts/Top platform 1.stp
30.0 x 65.6 x 35.0 mm

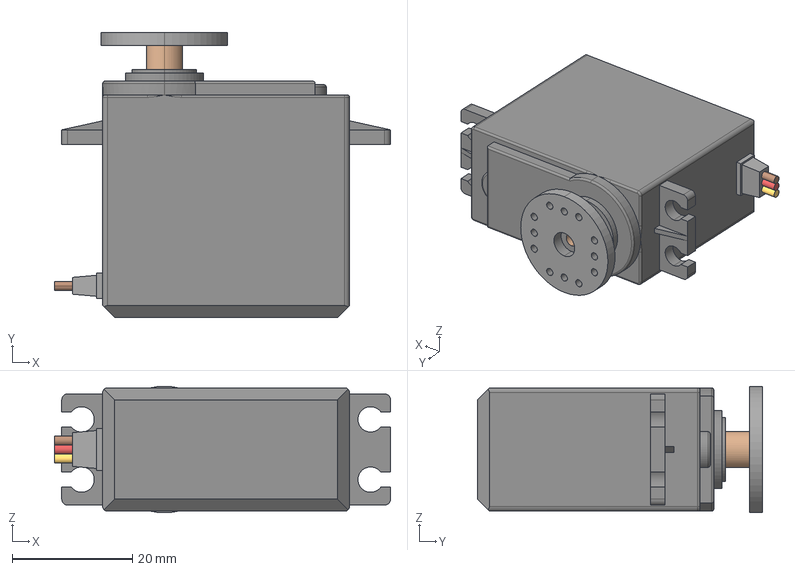
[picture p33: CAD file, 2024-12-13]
3D parts/Servo MG996R_r2.stp
55.8 x 47.4 x 21.0 mm

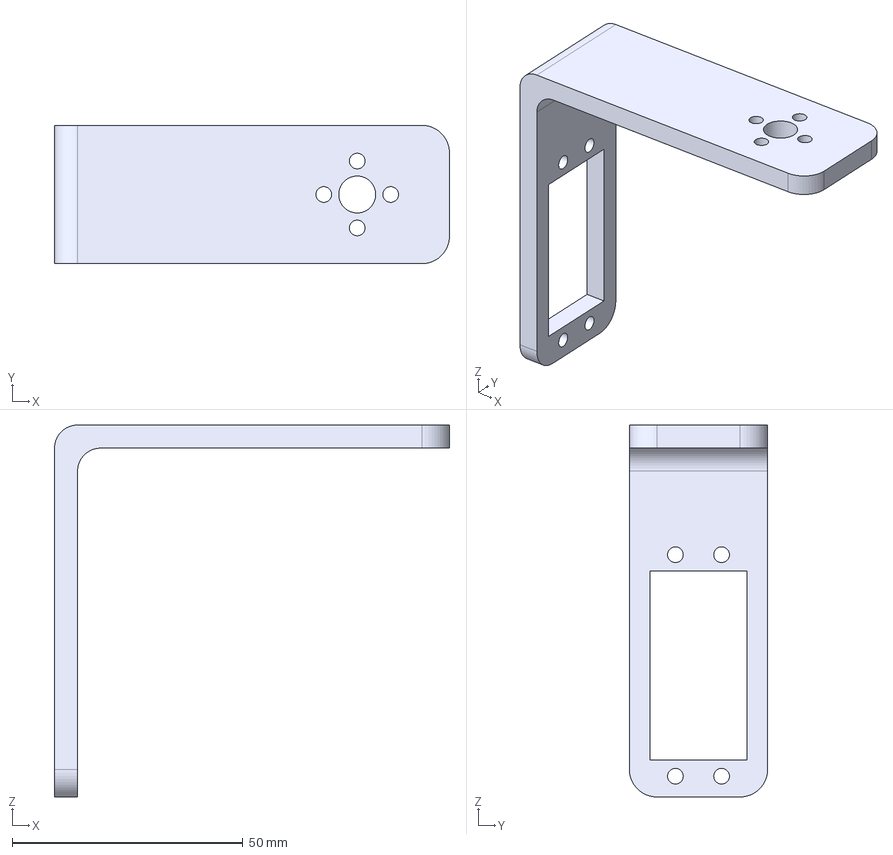
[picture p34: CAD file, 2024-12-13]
3D parts/base 2 .stp
85.6 x 30.0 x 80.6 mm

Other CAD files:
3D parts/Top platform 1.SLDPRT.sldprt

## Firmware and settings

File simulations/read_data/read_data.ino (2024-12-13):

#include <Wire.h>

const int MPU = 0x68;  // MPU6050 I2C address
float AccX, AccY, AccZ;
float GyroX, GyroY, GyroZ;
float accAngleX, accAngleY, gyroAngleX, gyroAngleY, gyroAngleZ;
float roll, pitch, yaw;
float AccErrorX, AccErrorY, GyroErrorX, GyroErrorY, GyroErrorZ;
float elapsedTime, currentTime, previousTime;
int c = 0;

void setup() {
  Serial.begin(19200);
  Wire.begin();                 // Initialize communication
  Wire.beginTransmission(MPU);  // Start communication with MPU6050
  Wire.write(0x6B);             // Talk to the register 6B
  Wire.write(0x00);             // Make reset - place a 0 into the 6B register
  Wire.endTransmission(true);   // End the transmission

  // Call this function if you need to get the IMU error values for your module
  calculate_IMU_error();
  delay(20);
}

void loop() {
  // === Read accelerometer data === //
  Wire.beginTransmission(MPU);
  Wire.write(0x3B);  // Start with register 0x3B (ACCEL_XOUT_H)
  Wire.endTransmission(false);
  Wire.requestFrom(MPU, 6, true);  // Read 6 registers total, each axis value is stored in 2 registers

  AccX = (Wire.read() << 8 | Wire.read()) / 16384.0;  // X-axis value
  AccY = (Wire.read() << 8 | Wire.read()) / 16384.0;  // Y-axis value
  AccZ = (Wire.read() << 8 | Wire.read()) / 16384.0;  // Z-axis value

  // Calculating Roll and Pitch from the accelerometer data
  accAngleX = (atan(AccY / sqrt(pow(AccX, 2) + pow(AccZ, 2))) * 180 / PI) + 0.95;       // AccErrorX
  accAngleY = (atan(-1 * AccX / sqrt(pow(AccY, 2) + pow(AccZ, 2))) * 180 / PI) + 1.38;  // AccErrorY

  // === Read gyroscope data === //
  previousTime = currentTime;                         // Previous time is stored before the actual time read
  currentTime = millis();                             // Current time actual time read
  elapsedTime = (currentTime - previousTime) / 1000;  // Divide by 1000 to get seconds

  Wire.beginTransmission(MPU);
  Wire.write(0x43);  // Gyro data first register address 0x43
  Wire.endTransmission(false);
  Wire.requestFrom(MPU, 6, true);  // Read 4 registers total, each axis value is stored in 2 registers

  GyroX = (Wire.read() << 8 | Wire.read()) / 131.0;  // For a 250deg/s range we have to divide first the raw value by 131.0, according to the datasheet
  GyroY = (Wire.read() << 8 | Wire.read()) / 131.0;
  GyroZ = (Wire.read() << 8 | Wire.read()) / 131.0;

  // Correct the outputs with the calculated error values
  GyroX = GyroX - 1.39;  // GyroErrorX
  GyroY = GyroY - 1.49;  // GyroErrorY
  GyroZ = GyroZ + 0.43;  // GyroErrorZ

  // Currently the raw values are in degrees per seconds, deg/s, so we need to multiply by seconds (s) to get the angle in degrees
  gyroAngleX = gyroAngleX + GyroX * elapsedTime;  // deg/s * s = deg
  gyroAngleY = gyroAngleY + GyroY * elapsedTime;
  yaw = yaw + GyroZ * elapsedTime;

  // Complementary filter - combine accelerometer and gyro angle values
  gyroAngleX = 0.96 * gyroAngleX + 0.04 * accAngleX;
  gyroAngleY = 0.96 * gyroAngleY + 0.04 * accAngleY;

  roll = gyroAngleX;
  pitch = gyroAngleY;

  // Print the values on the serial monitor
  Serial.print(roll);
  Serial.print("/");
  Serial.print(pitch);
  Serial.print("/");
  Serial.println(yaw);
}

void calculate_IMU_error() {
  // We can call this function in the setup section to calculate the accelerometer and gyro data error.
  // Place the IMU flat in order to get proper values for error calculation.

  // Read accelerometer values 200 times
  while (c < 200) {
    Wire.beginTransmission(MPU);
    Wire.write(0x3B);
    Wire.endTransmission(false);
    Wire.requestFrom(MPU, 6, true);

    AccX = (Wire.read() << 8 | Wire.read()) / 16384.0;
    AccY = (Wire.read() << 8 | Wire.read()) / 16384.0;
    AccZ = (Wire.read() << 8 | Wire.read()) / 16384.0;

    // Sum all readings
    AccErrorX = AccErrorX + ((atan((AccY) / sqrt(pow((AccX), 2) + pow((AccZ), 2))) * 180 / PI));
    AccErrorY = AccErrorY + ((atan(-1 * (AccX) / sqrt(pow((AccY), 2) + pow((AccZ), 2))) * 180 / PI));
    c++;
  }

  // Divide the sum by 200 to get the error value
  AccErrorX = AccErrorX / 200;
  AccErrorY = AccErrorY / 200;
  c = 0;

  // Read gyro values 200 times
  while (c < 200) {
    Wire.beginTransmission(MPU);
    Wire.write(0x43);
    Wire.endTransmission(false);
    Wire.requestFrom(MPU, 6, true);

    GyroX = Wire.read() << 8 | Wire.read();
    GyroY = Wire.read() << 8 | Wire.read();
    GyroZ = Wire.read() << 8 | Wire.read();

    // Sum all readings
    GyroErrorX = GyroErrorX + (GyroX / 131.0);
    GyroErrorY = GyroErrorY + (GyroY / 131.0);
    GyroErrorZ = GyroErrorZ + (GyroZ / 131.0);
    c++;
  }

  // Divide the sum by 200 to get the error value
  GyroErrorX = GyroErrorX / 200;
  GyroErrorY = GyroErrorY / 200;
  GyroErrorZ = GyroErrorZ / 200;

  // Print the error values on the Serial Monitor
  Serial.print("AccErrorX: ");
  Serial.println(AccErrorX);
  Serial.print("AccErrorY: ");
  Serial.println(AccErrorY);
  Serial.print("GyroErrorX: ");
  Serial.println(GyroErrorX);
  Serial.print("GyroErrorY: ");
  Serial.println(GyroErrorY);
  Serial.print("GyroErrorZ: ");
  Serial.println(GyroErrorZ);
}

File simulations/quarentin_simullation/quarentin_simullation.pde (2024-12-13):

// I2C device class (I2Cdev) demonstration Processing sketch for MPU6050 DMP output
// 6/20/2012 by Jeff Rowberg <jeff@rowberg.net>
// Updates should (hopefully) always be available at https://github.com/jrowberg/i2cdevlib
//
// Changelog:
//     2012-06-20 - initial release

/* ============================================
I2Cdev device library code is placed under the MIT license
Copyright (c) 2012 Jeff Rowberg

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
THE SOFTWARE IS PROVIDED "AS IS", WITHOUT WARRANTY OF ANY KIND, EXPRESS OR
IMPLIED, INCLUDING BUT NOT LIMITED TO THE WARRANTIES OF MERCHANTABILITY,
FITNESS FOR A PARTICULAR PURPOSE AND NONINFRINGEMENT. IN NO EVENT SHALL THE
AUTHORS OR COPYRIGHT HOLDERS BE LIABLE FOR ANY CLAIM, DAMAGES OR OTHER
LIABILITY, WHETHER IN AN ACTION OF CONTRACT, TORT OR OTHERWISE, ARISING FROM,
OUT OF OR IN CONNECTION WITH THE SOFTWARE OR THE USE OR OTHER DEALINGS IN
THE SOFTWARE.
===============================================
*/

import processing.serial.*;
import processing.opengl.*;
import toxi.geom.*;
import toxi.processing.*;

// NOTE: requires ToxicLibs to be installed in order to run properly.
// 1. Download from http://toxiclibs.org/downloads
// 2. Extract into [userdir]/Processing/libraries
//    (location may be different on Mac/Linux)
// 3. Run and bask in awesomeness

ToxiclibsSupport gfx;

Serial port;                         // The serial port
char[] teapotPacket = new char[14];  // InvenSense Teapot packet
int serialCount = 0;                 // current packet byte position
int synced = 0;
int interval = 0;

float[] q = new float[4];
Quaternion quat = new Quaternion(1, 0, 0, 0);

void setup() {
    // 300px square viewport using OpenGL rendering
    size(600,600, OPENGL);
    gfx = new ToxiclibsSupport(this);

    // setup lights and antialiasing
    lights();
    smooth();
  
    // display serial port list for debugging/clarity
    println(Serial.list());

    // specify the serial port
    String portName = "COM5";
    
    // open the serial port
    port = new Serial(this, portName, 115200);
    
    // send single character to trigger DMP init/start
    // (expected by MPU6050_DMP6 example Arduino sketch)
    port.write('r');
}

void draw() {
    if (millis() - interval > 1000) {
        // resend single character to trigger DMP init/start
        // in case the MPU is halted/reset while applet is running
        port.write('r');
        interval = millis();
    }
    
    // black background
    background(0);
    
    // translate everything to the middle of the viewport
    pushMatrix();
    translate(width / 2, height / 2);

    // toxiclibs direct angle/axis rotation from quaternion (NO gimbal lock!)
    // (axis order [1, 3, 2] and inversion [-1, +1, +1] is a consequence of
    // different coordinate system orientation assumptions between Processing
    // and InvenSense DMP)
    float[] axis = quat.toAxisAngle();
    rotate(axis[0], -axis[1], axis[3], axis[2]);

    // draw main body in red
    fill(255, 0, 0, 200);
    box(10, 10, 200);
    
    // draw front-facing tip in blue
    fill(0, 0, 255, 200);
    pushMatrix();
    translate(0, 0, -120);
    rotateX(PI/2);
    drawCylinder(0, 20, 20, 8);
    popMatrix();
    
    // draw wings and tail fin in green
    fill(0, 255, 0, 200);
    beginShape(TRIANGLES);
    vertex(-100,  2, 30); vertex(0,  2, -80); vertex(100,  2, 30);  // wing top layer
    vertex(-100, -2, 30); vertex(0, -2, -80); vertex(100, -2, 30);  // wing bottom layer
    vertex(-2, 0, 98); vertex(-2, -30, 98); vertex(-2, 0, 70);  // tail left layer
    vertex( 2, 0, 98); vertex( 2, -30, 98); vertex( 2, 0, 70);  // tail right layer
    endShape();
    beginShape(QUADS);
    vertex(-100, 2, 30); vertex(-100, -2, 30); vertex(  0, -2, -80); vertex(  0, 2, -80);
    vertex( 100, 2, 30); vertex( 100, -2, 30); vertex(  0, -2, -80); vertex(  0, 2, -80);
    vertex(-100, 2, 30); vertex(-100, -2, 30); vertex(100, -2,  30); vertex(100, 2,  30);
    vertex(-2,   0, 98); vertex(2,   0, 98); vertex(2, -30, 98); vertex(-2, -30, 98);
    vertex(-2,   0, 98); vertex(2,   0, 98); vertex(2,   0, 70); vertex(-2,   0, 70);
    vertex(-2, -30, 98); vertex(2, -30, 98); vertex(2,   0, 70); vertex(-2,   0, 70);
    endShape();
    
    popMatrix();
}

void serialEvent(Serial port) {
    interval = millis();
    while (port.available() > 0) {
        int ch = port.read();

        if (synced == 0 && ch != '$') return;   // initial synchronization - also used to resync/realign if needed
        synced = 1;
        print ((char)ch);

        if ((serialCount == 1 && ch != 2)
            || (serialCount == 12 && ch != '\r')
            || (serialCount == 13 && ch != '\n'))  {
            serialCount = 0;
            synced = 0;
            return;
        }

        if (serialCount > 0 || ch == '$') {
            teapotPacket[serialCount++] = (char)ch;
            if (serialCount == 14) {
                serialCount = 0; // restart packet byte position
                
                // get quaternion from data packet
                q[0] = ((teapotPacket[2] << 8) | teapotPacket[3]) / 16384.0f;
                q[1] = ((teapotPacket[4] << 8) | teapotPacket[5]) / 16384.0f;
                q[2] = ((teapotPacket[6] << 8) | teapotPacket[7]) / 16384.0f;
                q[3] = ((teapotPacket[8] << 8) | teapotPacket[9]) / 16384.0f;
                for (int i = 0; i < 4; i++) if (q[i] >= 2) q[i] = -4 + q[i];
                
                // set our toxilibs quaternion to new data
                quat.set(q[0], q[1], q[2], q[3]);
            }
        }
    }
}

void drawCylinder(float topRadius, float bottomRadius, float tall, int sides) {
    float angle = 0;
    float angleIncrement = TWO_PI / sides;
    beginShape(QUAD_STRIP);
    for (int i = 0; i < sides + 1; ++i) {
        vertex(topRadius*cos(angle), 0, topRadius*sin(angle));
        vertex(bottomRadius*cos(angle), tall, bottomRadius*sin(angle));
        angle += angleIncrement;
    }
    endShape();
    
    // If it is not a cone, draw the circular top cap
    if (topRadius != 0) {
        angle = 0;
        beginShape(TRIANGLE_FAN);
        
        // Center point
        vertex(0, 0, 0);
        for (int i = 0; i < sides + 1; i++) {
            vertex(topRadius * cos(angle), 0, topRadius * sin(angle));
            angle += angleIncrement;
        }
        endShape();
    }
  
    // If it is not a cone, draw the circular bottom cap
    if (bottomRadius != 0) {
        angle = 0;
        beginShape(TRIANGLE_FAN);
    
        // Center point
        vertex(0, tall, 0);
        for (int i = 0; i < sides + 1; i++) {
            vertex(bottomRadius * cos(angle), tall, bottomRadius * sin(angle));
            angle += angleIncrement;
        }
        endShape();
    }
}

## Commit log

2024-12-13 Add files via upload
    The SysML for a gimbal project captures the system's structure and behavior, detailing components like sensors, motors, and controllers. This folder includes UC diagram (Use Case ) representing the i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
2024-12-13 Add files via upload
    Testing 2 ways of detecting camera movements : Complementary Filter/ DMP (Digital Motion Processor).
2024-12-13 Create Circuit
2024-12-13 Update Circuit
2025-01-22 Rename Copy of Use case diagram.png to Use case diagram.png
